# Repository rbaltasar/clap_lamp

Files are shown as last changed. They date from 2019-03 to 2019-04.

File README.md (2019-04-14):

# Clap lamp project
This project is about a device able to control a LED light by clapping:
* Two claps for switch ON/OFF
* Three claps for color change

This can be used with almost any lamp that is controlled by a IR remote control, as long as:
* You know the IR commands for ON and OFF.
* You know which IR protocol is used, and this protocol is supported by the Arduino-IRremote library.

A clap is detected if the following conditions are met:
* The measured sound level is higher than a defined threshold.
* The measured sound's most dominant frequency lies within a defined frequency range.
Below is explained how to tune these two parameters.

A sequence of claps is considered to be detected if the following conditions are met:
1. A first clap is detected after a period of more than 1 second without detecting any clap.
2. Further claps are detected within a period of [80-400] milliseconds after the previous clap.
3. No clap is detected in a period of [160-400] milliseconds after the previous clap.

Depending on the number of detected claps in the sequence:
* If 2: an ON/OFF command (depending on the current state of the lamp) will be issued.
* If 3: a change color command will be issued.
* If > 3: the sequence will be ignored.

# The hardware
For this project you will need at least:
* Arduino Uno (or similar microcontroller. See below).
* IR emitter.
* Microphone. I have tested it with MAX4466 and MAX9814.
* Power supply.

Those components are enough for a functional implementation. To make it good looking, I added the following:
* Led (to give feedback about the clap detection).
* Arduino Uno prototyping shield (to solder all the components together).

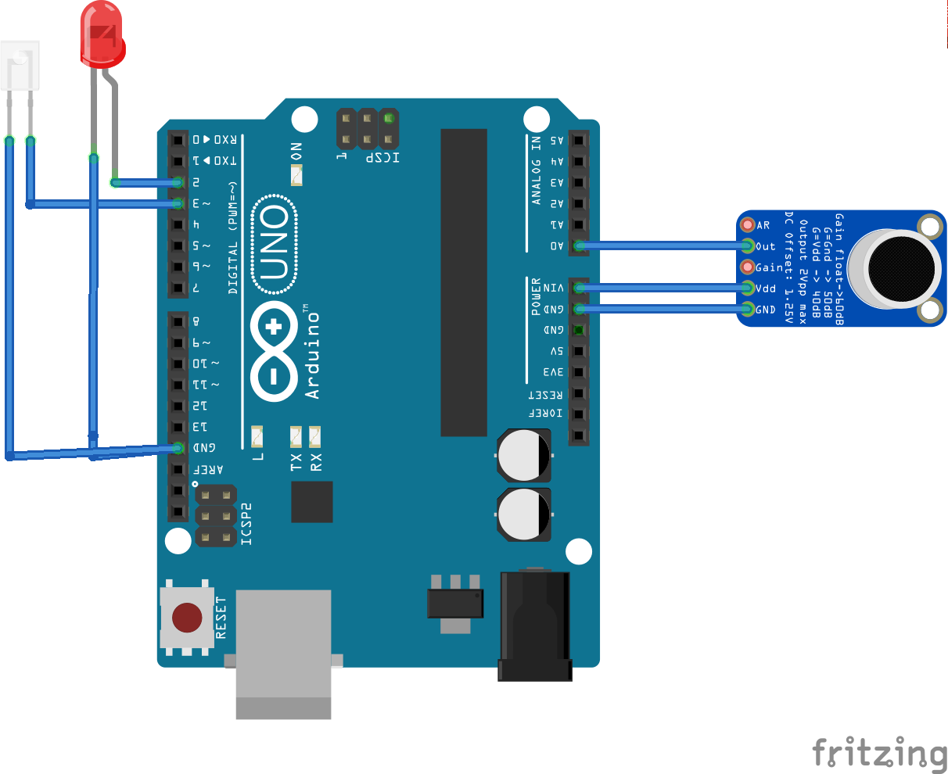
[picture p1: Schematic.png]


# The software
## Installation
Getting the software up and running is as easy as cloning this repository (don't forget to include submodules for the Arduino-IRremote library) and flashing it to your Arduino.
I have developed it using an Arduino Uno, but I have always used the abstracted Arduino IDE API, so it should work with another Arduinos as well.
This can also be adapted to ESP12 by indicating the GPIO pin for the IR Emitter. An example can be found in: https://github.com/rbaltasar/home_automation/tree/master/bedroom_node
For the moment the Arduino-IRremote library does not support ESP32.

## Clap detection tuning
Once the hardware is ready and the software flashed, you should be able to clap twice and see the red LED blinking.
If this is not happening, there are many things that may have gone wrong. Here we will focus on tuning the clap detection.
First of all consider the conditions mentioned above. If you clap too fast or too slow, it will not work.
If you believe that you are clapping well but still not working, try tune the following parameters in config.h:
* SOUND_THRESHOLD: minimum value of the maximum amplitude (in time) within a group of samples. The lower the value, the more sensitive the device is.
* MAX_FREQ & MIN_FREQ: frequency spectrum where a clap may be. The larger the range, the more sensitive the device is, but also the less noise it filters.

The best way to tune it is by switching on the debug traces and to look at the output with and without claps, and adapt the configuration parameters to your claps, microphone, ambient noise...

If you see the led blinking when you clap twice, you are good to go to the next step.

## IR tuning
Most of the cheap LED lights use the same protocol (NEC) and commands to switch it on and off. If you are lucky, you have nothing to do here.
If not, the best way to figure out what protocol and commands you lamp respond to, is the following (you need additional hardware):
1. Upload the IR sniffer sketch to an Arduino.
2. Connect an IR receiver to your Arduino.
3. Sniff the commands from your IR remote. Update the my code with the right commands and protocol.

# The case
One it is functionally working, you will realize the whole thing is quite ugly to just let it stay like that.
Therefore I designed a basic case that can be 3D printed and that will hide all this ugliness. The 3D model can also be found in this repository.

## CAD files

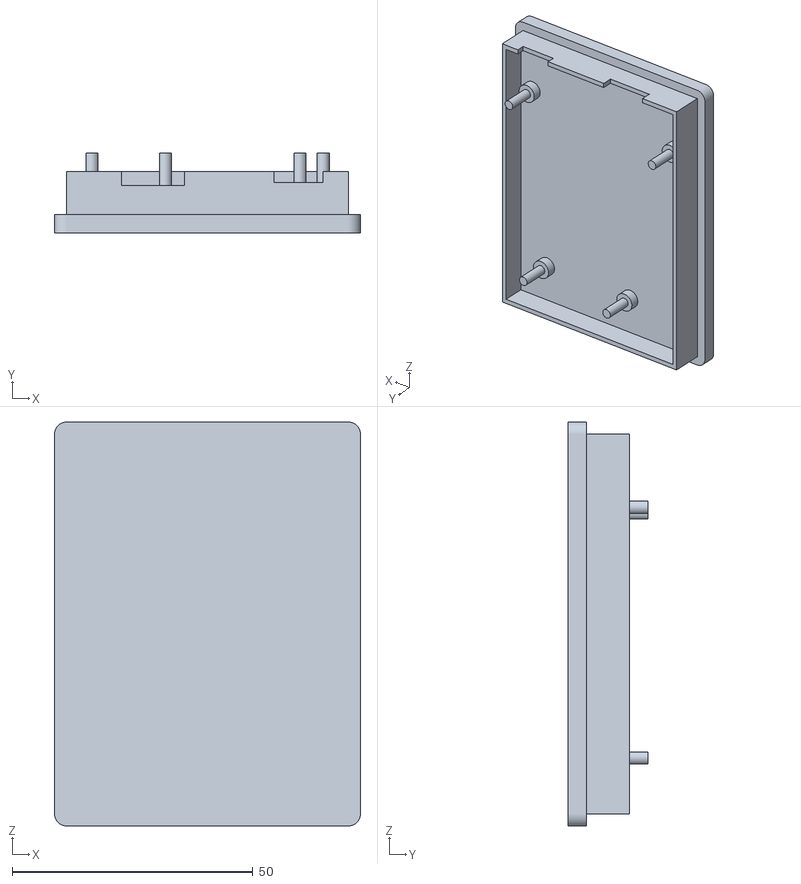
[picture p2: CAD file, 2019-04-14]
3D_Model/clap_lamp_bottom.stl
63.5 x 16.5 x 83.8

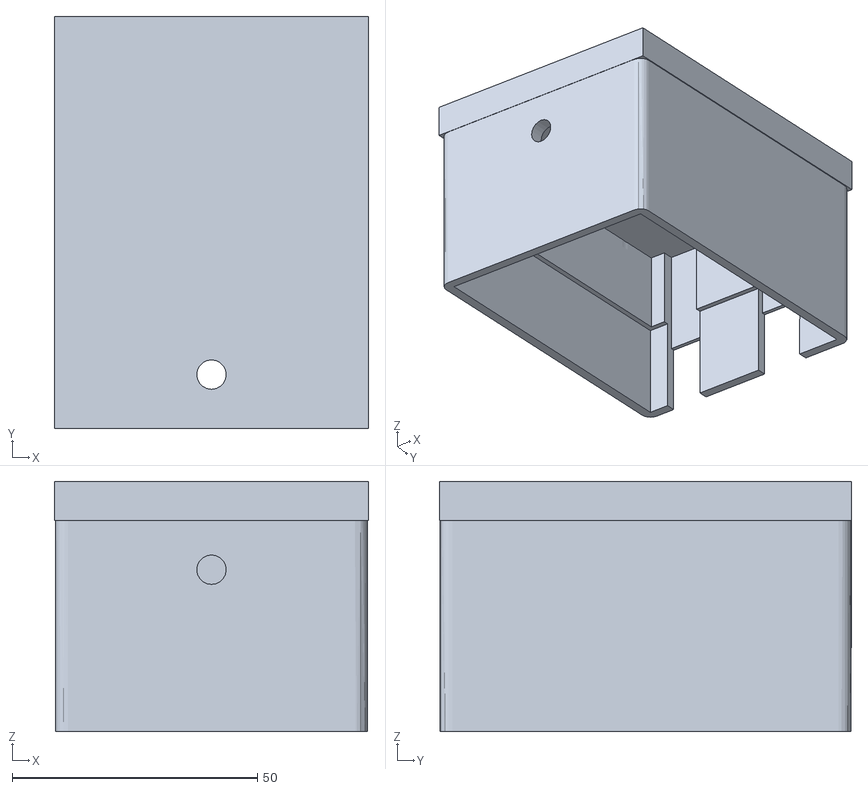
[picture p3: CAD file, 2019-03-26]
3D_Model/clap_lamp_top.stl
64.0 x 84.0 x 51.0

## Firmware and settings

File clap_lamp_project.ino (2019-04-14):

/* Includes */
#include "RGB_to_IR.h"
#include "frequency_utilities.h"
#include "clapDetection.h"

#if DEBUG_TRACES_FREQ
#include "serialFreqDisplay.h" //Only for frequency debugging
#endif

/* IR utilities */
RGB_to_IR ir_sender;

/* Audio signal spectrum display */
#if DEBUG_TRACES_FREQ
SerialFreqDisplay displ(THRESHOLD, NSAMPLES/2);
#endif

/* Audio signal analyzer */
FrequencyUtilities FreqUtilities;

/* Clap detection features */
clapDetection clap_detector(&FreqUtilities);

/* Clap detection variables */
uint8_t next_color_idx = 0;
bool lamp_state = false;

/* Setup */
void setup() {

#if DEBUG_TRACES_GENERAL
  Serial.begin(115200);
#endif
 
  /* Share the serial printer object for debugging functionalities */
  HardwareSerial* hwPrint;
  hwPrint = &Serial;
  ir_sender.configure(hwPrint);
  FreqUtilities.begin(hwPrint);

  /* LED */
  pinMode(LED_PIN, OUTPUT);

  /* Startup effect */
  set_led(true);
  delay(500);
  set_led(false);
  delay(500);
  set_led(true);
  delay(500);
  set_led(false);
  delay(500);
  set_led(true);
  delay(500);
  set_led(false);
}

/* Set LED */
void set_led(bool state)
{
  if(state)
  {
    digitalWrite(LED_PIN, HIGH);
  }
  else digitalWrite(LED_PIN, LOW);
}

/* Device-specific logic */
void device_logic()
{
 
  /* Process double clap detected --> Switch ON/OFF */
  if(clap_detector.getDetectionType() == DOUBLE_CLAP)
  {
    if(lamp_state)
    {
      set_led(true);
      ir_sender.send_ir_off();
      lamp_state = false;
      delay(1000);
      set_led(false);
    }
    else
    {
      set_led(true);
      ir_sender.send_ir_on();
      lamp_state = true;
      delay(1000);
      set_led(false);
    } 
    clap_detector.resetDetectionType();
  } 

  /* Process triple clap detected --> Change color */
  else if(clap_detector.getDetectionType() == TRIPLE_CLAP)
  {   
    ir_sender.send_ir_colorIdx(next_color_idx++);
    next_color_idx >= NUM_IR_COLORS ? next_color_idx = 0 : next_color_idx = next_color_idx;
    clap_detector.resetDetectionType();
    int i=0;
    while(i<10)
    {
      set_led(true);
      delay(100);
      set_led(false);
      delay(100);
      i++;
    } 
  }
}

void loop() 
{ 
  /* Feed the clap detector algorithm. Apply logic if anything detected */
  if(clap_detector.feed()) device_logic();
}

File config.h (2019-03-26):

#if !defined CONFIG_H
#define CONFIG_H

//IR sender configuration
#define LED_PIN 2
#define SEND_REPETITION_PERIOD 200//Delay between send repetitions
#define SEND_REPETITIONS 2//Amount of send repetitions for a single command

//FFT configuration
#define NSAMPLES 64

//Clap configuration
#define SOUND_THRESHOLD 530 //Needs to be calibrated
#define MAX_FREQ (5*NSAMPLES)/6
#define MIN_FREQ NSAMPLES/10

//---------- Debugging ------------------
#define DEBUG_TRACES_TIME 0
#define DEBUG_TRACES_FREQ 0
#define DEBUG_TRACES_GENERAL 0

#endif

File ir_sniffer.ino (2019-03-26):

#include <IRremote.h>
#define RECV_PIN 8
IRrecv irrecv(RECV_PIN);
decode_results results;

void setup(){
  irrecv.enableIRIn();
  pinMode(RECV_PIN,INPUT);
  Serial.begin(115200);
}

void loop(){

  if (irrecv.decode(&results))
  {
    Serial.println(results.value, HEX);
    switch (results.decode_type){
        case NEC: Serial.println("NEC"); break ;
        case SONY: Serial.println("SONY"); break ;
        case RC5: Serial.println("RC5"); break ;
        case RC6: Serial.println("RC6"); break ;
        case DISH: Serial.println("DISH"); break ;
        case SHARP: Serial.println("SHARP"); break ;
        case JVC: Serial.println("JVC"); break ;
        case SANYO: Serial.println("SANYO"); break ;
        case MITSUBISHI: Serial.println("MITSUBISHI"); break ;
        case SAMSUNG: Serial.println("SAMSUNG"); break ;
        case LG: Serial.println("LG"); break ;
        case WHYNTER: Serial.println("WHYNTER"); break ;
        case AIWA_RC_T501: Serial.println("AIWA_RC_T501"); break ;
        case PANASONIC: Serial.println("PANASONIC"); break ;
        case DENON: Serial.println("DENON"); break ;
      default:
        case UNKNOWN: Serial.println("UNKNOWN"); break ;
      }
    irrecv.resume();
  }
}

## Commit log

2019-03-26 Updated Readme. Added schematic. Added IR sniffer. Added case top 3D model
    [clap_lamp_top.stl]
2019-03-26 Cleaned code
    [clap_lamp_top.stl]
2019-04-14 Added IR color list to RGB_to_IR Refactored clap detection algorithm into its own class Added functionality to detect a third clap Added feature to change color when third clap detected Fixed multipl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
    [clapDetection.cpp, clap_lamp_project.ino]
